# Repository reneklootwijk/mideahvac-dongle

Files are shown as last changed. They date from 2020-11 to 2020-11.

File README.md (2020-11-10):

# Midea HVAC WiFi Dongle

This repository contains the hardware design of a WiFi dongle for Midea-like airconditioners and humidifiers.
Midea provides a WiFi dongle (SK102/SK103), either as optional feature or built-in, to control the appliances via a mobile application. This dongle uses and is dependent on the Midea cloud which does not expose a publically available API. The protocol used by the dongle has been reverse engineered, but newer version still require the cloud to obtain an encryption key or require an addition server simulating the Midea cloud. This means integration in an existing home automation system is not straight forward.

Besides the protocol the dongle uses to commumicate with the mobile app and the cloud, also the protocol that is used between the dongle and the appliances has been reverse engineered (at least the most important parts). This means the original dongle can be replaced by a custom dongle making it independent on any cloud.

Besides Midea itself other vendors of these type of appliances are also using the Midea cloud and dongle to support control via a mobile app. Examples of these vendors are:

* Qlima
* Artel
* Carrier
* Toshiba
* Idema

This design of a custom dongle can be used to replace the orignal dongle with a type A USB connector. The version with with a JST-XH connector needs a slight modification.

## Technical design

The design of the dongle is based on an ESP-12 which provides the WiFi interface and microcontroller to communicate with the appliance. Because the interface of the appliance is a 5V TTL serial port (UART) and the ESP-12 uses 3.3V and is not 5V tolerant, we need level shifters for the communication and a power regulator in order to power the dongle from the appliance.

The design has been made in KiCad and all files can be found in the KiCad directory.

<p align="center">
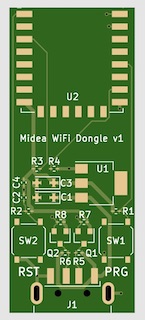
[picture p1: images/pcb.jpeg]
  <br/>
  <em>The KiCad PCB design</em>
</p>

Note: The resulting PCB including the ESP-12 turned out to be 1 mm to long to fit into the location of the original dongle (in my Artel airconditioner). It was easy to locate it somewhere else, but pay attention whether the PCB would fit in your appliance. The dimensions of the dongle are: 55mmx20mm (l*w) without casing.

## Ordering and manufacturing

The PCB can be ordered by the manufacturer of your choosing. I had it manufactured and partly assembled by [JLCPCB](https://jlcpcb.com/). The files required to order the PCB including the SMT assembly of all components except the ESP-12 and USB connector can be found in the JLCPCB directory.

<p align="center">
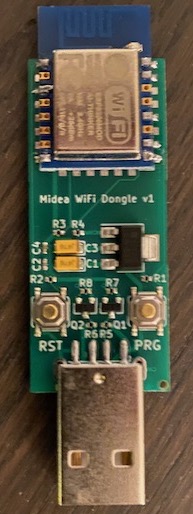
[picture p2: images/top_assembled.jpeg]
  <br/>
  <em>The assembled PCB</em>
</p>

The JLCPCB directory contains the following files:

* Gerber-Midea WiFi Dongle v1.zip, this zip contains all gerber files and the drill file.
* BOM-Midea WiFi Dongle.csv, this is the Bill Of Material file.
* CPL-Midea WiFi Dongle.csv, this is the Pick and Place file

Note: The ESP-12 and USB connector are not part of the BOM and need to be ordered somewhere else, JLCPCB could not deliver them. This also means you have to solder them yourself.

## Case

I also designed a case that can printed on a 3d printer. The .STL file is part of this repository.

<p align="center">
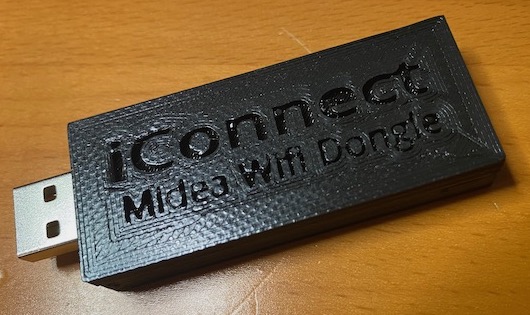
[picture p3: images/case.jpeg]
  <br/>
  <em>The 3D printed case</em>
</p>

## Firmware

At this moment there are several options:
* Sören Beye created firmware to integrate dehumidifiers with Home Assistant: https://github.com/Hypfer/esp8266-midea-dehumidifier.
* Sergey V. Dudanov created an extension for ESPHome integrating aircondititioners with Home Assistant: https://github.com/dudanov/esphome.
* I created a node.js module to integrate airconditioners with anything you like, but you need to program: https://github.com/reneklootwijk/node-mideahvac. The firmware required on the dongle is esplink, a serial bridge: https://github.com/jeelabs/esp-link.
* To reverse engineer the protocol the original dongle is using to communicate with your appliance, you can use this custom dongle to capture this communication. See https://github.com/reneklootwijk/midea-uartsniffer.

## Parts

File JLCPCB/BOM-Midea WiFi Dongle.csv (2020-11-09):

Comment | Designator | Footprint | LCSC Part #
PRG | SW1 | SMD-SW-4_5.1x5.1x1.7 | C318889
RST | SW2 | SMD-SW-4_5.1x5.1x1.7 | C318889
BSS138 | Q1 | SOT-23 | C426569
BSS138 | Q2 | SOT-23 | C426569
100nF | C4 | 0402 | C1525
10k | R5 | 0402 | C25744
10k | R7 | 0402 | C25744
10k | R6 | 0402 | C25744
10k | R8 | 0402 | C25744
LM1117-3.3 | U1 | SOT-223 | C126027
47uF | C3 | CASE-A_3216 | C185773
47uF | C1 | CASE-A_3216 | C185773
10k | R1 | 0402 | C25744
10k | R2 | 0402 | C25744
10k | R3 | 0402 | C25744
10k | R4 | 0402 | C25744
470uF | C2 | 0402 | C1537

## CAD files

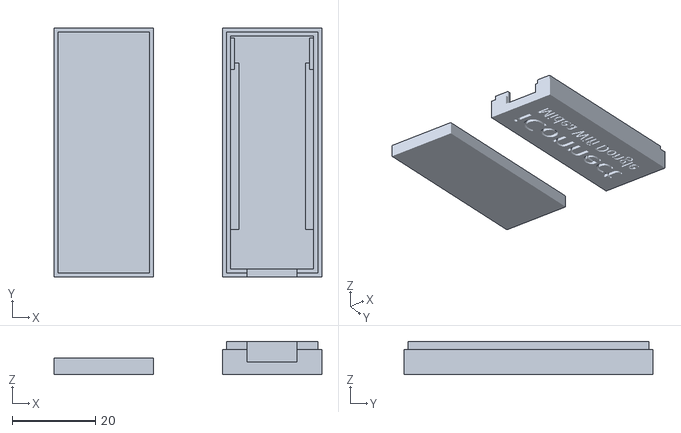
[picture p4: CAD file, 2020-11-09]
Case - Midea Wifi Dongle.stl
64.5 x 60.0 x 8.00

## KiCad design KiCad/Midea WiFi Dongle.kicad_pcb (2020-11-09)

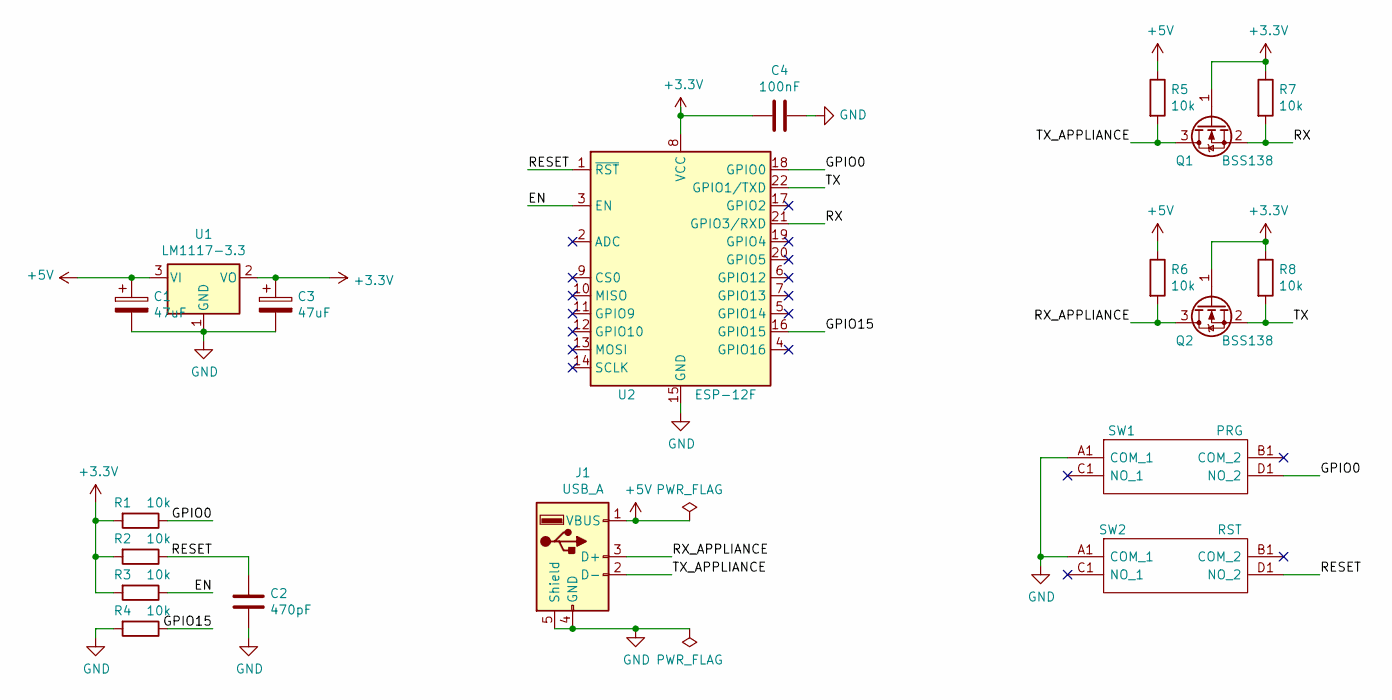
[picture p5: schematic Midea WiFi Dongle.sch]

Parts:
C1, C3: 47uF; CP_EIA-3216-10_Kemet-I; LCSC C185773
C2: 470pF; C_0402_1005Metric
C4: 100nF; C_0402_1005Metric
J1: USB_A; USB_A_CNCTech_1001-011-01101_Horizontal
Q1, Q2: BSS138; SOT-23; LCSC C426569
R1, R2, R3, R4, R5, R6, R7, R8: 10k; R_0402_1005Metric; LCSC C25744
SW1: PRG; TS1187AXXX; Manufacturer_Part_Number TS-1187A-C-C-B; LCSC C318889
SW2: RST; TS1187AXXX; Manufacturer_Part_Number TS-1187A-C-C-B; LCSC C318889
U1: LM1117-3.3; SOT-223; LCSC C126027
U2: ESP-12F; ESP-12E

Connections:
+3V3: C3.1, C4.2, Q1.1 (G), Q2.1 (G), R1.2, R2.2, R3.2, R7.1, R8.1, U1.2 (VO), U2.8 (VCC)
+5V: C1.1, J1.1 (VBUS), R5.1, R6.1, U1.3 (VI)
/EN: R3.1, U2.3 (EN)
/GPIO0: R1.1, SW1.D1 (NO_2), U2.18 (GPIO0)
/GPIO15: R4.1, U2.16 (GPIO15)
/RESET: C2.1, R2.1, SW2.D1 (NO_2), U2.1 (~RST)
/RX: Q1.2 (S), R7.2, U2.21 (GPIO3/RXD)
/RX_APPLIANCE: J1.3 (D+), Q2.3 (D), R6.2
/TX: Q2.2 (S), R8.2, U2.22 (GPIO1/TXD)
/TX_APPLIANCE: J1.2 (D-), Q1.3 (D), R5.2
GND: C1.2, C2.2, C3.2, C4.1, J1.4 (GND), J1.5 (Shield), R4.2, SW1.A1 (COM_1), SW2.A1 (COM_1), U1.1 (GND), U2.15 (GND)

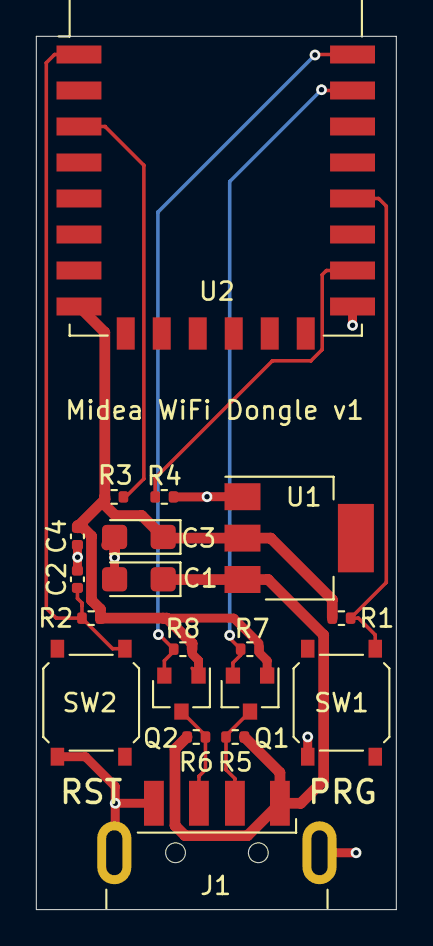
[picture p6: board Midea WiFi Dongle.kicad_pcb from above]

Board: 4 copper layers, 20.0 x 48.5 mm, 19 parts (0 on the bottom side), 11 nets.

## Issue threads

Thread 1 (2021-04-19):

JLC wants to know if it's ok that there is no copper trace on the inner layers

sebirdman, 2021-04-19:
Hello,

Hardware isn't my strong suit. I've submit the provided files to JLC, they're asking if having no copper trace on the inner layers is by design. Is this correct?

Thanks for everything here, this is a really nice project.

sebirdman, 2021-04-19:
Looks like based on some comments elsewhere that this should be a two layer pcb with no inner layers. Closing.

Closed 2021-04-19.

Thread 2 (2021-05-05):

Rene - Contact

njordan77, 2021-05-05:
Sorry Rene to open this threat but i've tried to get in touch with you and could not find any email address via Google. Will remove this communication threat as soon as i can get in touch.

I've following situation, Midea AC and i want/already prepare the Dongle. Only issue that i'm not using HA but Openhab with MQTT.  Sergey ment that its best to not use the current implementation but develop my own code or wait for you as you are in the process to provide a generic Library.

And that is my question: could you PLEASE give me a starting point to control my AC via MQTT. I know pubsubclient...so i would only need to know how i can control the AC via OpenDongle + Arduino IDE (ESP8266 ESP-01). Thanks a lot Norbert (norbert.jordan@gmail.com)

iamvlanone, 2021-05-05:
Hi, I hope I am not out of line, but I had a look at the article below and could control my AC using MQTT. I am using HA and it was not easy to integrate. So reverted to ESPHome. The author uses OpenHab and provides details on coding using IDE.

Apologies if you have already seen the article.

https://community.openhab.org/t/tutorial-connect-your-dumb-midea-ac-unit-to-openhab-with-mqtt/114994

reneklootwijk, 2021-05-05:
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

I just commited the C library you can use to create your own firmware. However, the documentation is far from finished and correct. See https://github.com/reneklootwijk/midea-uart.

Some time ago I published nodejs code to control an appliance via bridging firmware running on the custom dongle. This code contains a very simple example using MQTT. However, the features implemented in the nodejs code lack the current C library code. The nodejs code can be found here: https://github.com/reneklootwijk/node-mideahvac

njordan77, 2021-05-05:
Thanks a lot! That is more than i expected to receive in such a short time. i will try both approaches....

Closed 2021-05-05.

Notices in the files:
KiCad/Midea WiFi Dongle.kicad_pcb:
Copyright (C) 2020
